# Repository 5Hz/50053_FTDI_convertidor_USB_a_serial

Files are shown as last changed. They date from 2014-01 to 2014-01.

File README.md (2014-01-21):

Tarjeta FTDI (convertidor usb - serial) para Arduino - 5V
=========================================================



Esta tarjeta contiene un FTDI FT232RL para conversión USB a serial. El pinout de esta tarjeta es idéntico al de un cable FTDI para trabajar con tarjetas Arduino a 5V. Así mismo posee un jumper para configurarla a 3.3V o 5V tanto en niveles de alimentación como en I/O.

Para mas informacion puedes visitar la [**pagina del producto**](http://5hertz.com/index.php?main_page=product_info&cPath=67_68_130&products_id=470).

Contenidos del repositorio
--------------------------
Aqui puedes encontrar los archivos fuente de este dispositivo ordenados de la siguiente manera:

- **/Eagle** Archivos de diseño en Eagle (.brd, .sch)
- **/Arduino** Librerias y codigos ejemplo.

Informacion de la licencia
-------------------

* El hardware esta publicado bajo la licencia [Creative Commons Share-alike 3.0](http://creativecommons.org/licenses/by-sa/3.0/).
* Todo el contenido adicional es de *codigo abierto* *(open source)*, ten la libertad para utilizarlo como quieras.

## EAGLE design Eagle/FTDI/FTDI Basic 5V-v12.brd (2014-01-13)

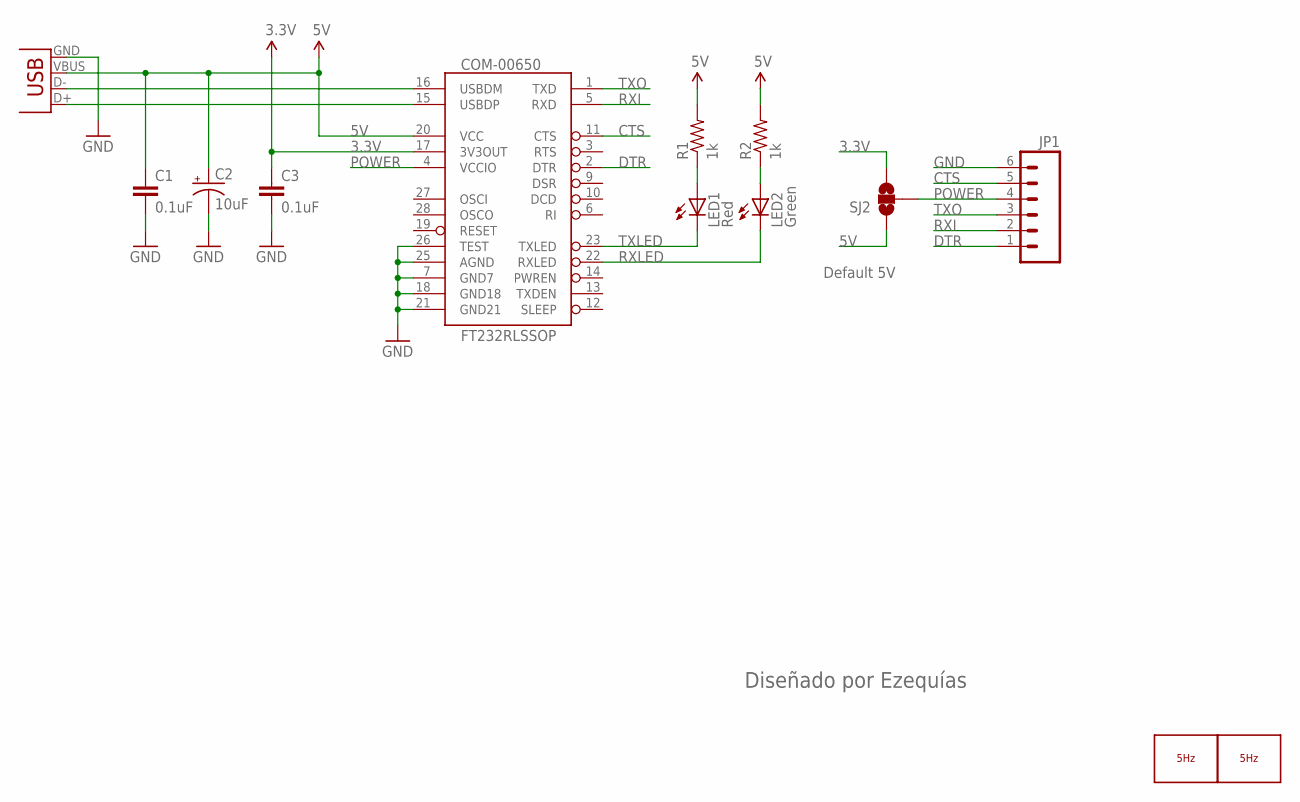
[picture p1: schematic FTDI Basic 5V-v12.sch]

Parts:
C1, C3: 0.1uF; 0603-CAP
C2: 10uF; EIA3216
COM-00650: FT232RLSSOP; SSOP28DB
JP1: M06SIP; 1X06
LED1: Red; LED-0603
LED2: Green; LED-0603
LOGO1: LOGO_5HZ_H_5MM; 5HZ_LOGO_H_5MM
LOGO2: LOGO_5HZ_H_15MM; 5HZ_LOGO_H_15MM
PRT-00587: 897-43-005-00-100001; USB-MINIB
R1, R2: 1k; 0603-RES
SJ2: SOLDERJUMPER_2WAYS; SJ_3

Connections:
3.3V: C3.1, COM-00650.17 (3V3OUT), SJ2.3
5V: C1.1, C2.A (+), COM-00650.20 (VCC), PRT-00587.VBUS, R1.2, R2.2, SJ2.1
CTS: COM-00650.11 (CTS), JP1.5
DTR: COM-00650.2 (DTR), JP1.1
GND: C1.2, C2.C (-), C3.2, COM-00650.7 (GND7), COM-00650.18 (GND18), COM-00650.21 (GND21), COM-00650.25 (AGND), COM-00650.26 (TEST), JP1.6, PRT-00587.GND
unnamed: LED1.A, R1.1
unnamed: LED2.A, R2.1
POWER: COM-00650.4 (VCCIO), JP1.4, SJ2.2
RXI: COM-00650.5 (RXD), JP1.2
RXLED: COM-00650.22 (RXLED), LED2.C
TXLED: COM-00650.23 (TXLED), LED1.C
TXO: COM-00650.1 (TXD), JP1.3
USB_D+: COM-00650.15 (USBDP), PRT-00587.D+
USB_D-: COM-00650.16 (USBDM), PRT-00587.D-

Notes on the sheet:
Default 5V
Diseñado por Ezequías

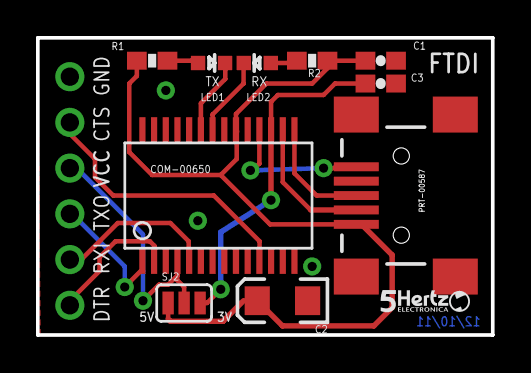
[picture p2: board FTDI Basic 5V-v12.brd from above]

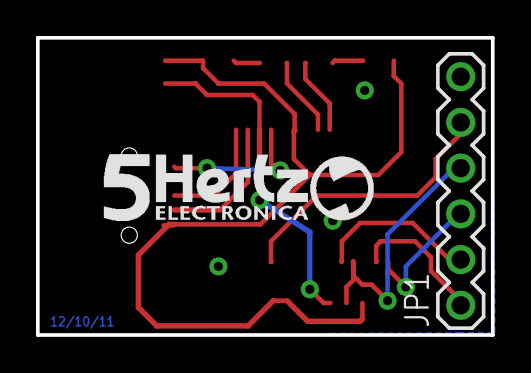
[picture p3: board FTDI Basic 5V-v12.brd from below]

Board: 2 copper layers, 25.3 x 16.5 mm, 13 parts (2 on the bottom side), 14 nets.
